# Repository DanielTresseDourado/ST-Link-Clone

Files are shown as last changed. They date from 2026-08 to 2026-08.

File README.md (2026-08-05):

# ST-Link Clone

Projeto desenvolvido na disciplina de Prototipagem do curso de Engenharia Elétrica da Universidade Estadual de Londrina (UEL).

Este repositório contém o desenvolvimento de uma placa compatível com o ST-Link para programação e depuração de microcontroladores STM32. O projeto foi concebido com foco na miniaturização do hardware e no desenvolvimento de uma PCB de alta densidade, empregando um encapsulamento Micro BGA e uma estrutura de seis camadas para atender aos requisitos de roteamento e integridade dos sinais.

## Placa

### Vista Superior
StLink top

### Vista Inferior
StLink bottom

## Conteúdo do repositório

- Projeto completo do Altium Designer
- Arquivos do projeto (.PrjPcb)
- Esquemáticos (.SchDoc)
- Layout da PCB (.PcbDoc)
- Bibliotecas de componentes esquemáticos e de PCB
- Arquivos de fabricação (Gerbers)

## Características

- Compatível com ST-Link para programação e depuração de microcontroladores STM32
- PCB de seis camadas
- Layout de alta densidade (HDI)
- Encapsulamento Micro BGA
- Formato compacto, com dimensões próximas às de um dongle USB
- Projeto desenvolvido no Altium Designer
- Documentação completa para edição e fabricação

## Autor

Daniel Tresse Dourado  
Engenharia Elétrica – Universidade Estadual de Londrina (UEL)

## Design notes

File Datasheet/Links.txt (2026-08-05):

micro STM32F103R8H6 -  https://www.digikey.com.br/en/products/detail/stmicroelectronics/STM32F103R8H6/2035336

Led Green - https://www.digikey.com.br/en/products/detail/w%C3%BCrth-elektronik/150040VS73240/8557157
Led Red - https://www.digikey.com.br/en/products/detail/w%C3%BCrth-elektronik/150040RS73240/8557156

Resistor Leds (0201) 560 ohm - https://www.digikey.com.br/en/products/detail/yageo/RC0201FR-07560RL/3202414

diodo schottky Single - https://www.digikey.com/en/products/detail/diodes-incorporated/BAT54WS-7-F/804865
resistor 0ohm(0201) - https://www.digikey.com.br/en/products/detail/yageo/RC0201JR-070RL/1948898

Capacitor 0.1uF - https://www.digikey.com/en/products/detail/murata-electronics/GRM155R71H104KE14D/4906220

Resistor 100k - https://www.digikey.com.br/en/products/detail/yageo/RC0201FR-07100KL/1948859

Resistor 1.5k - https://www.digikey.com.br/en/products/detail/yageo/RC0201JR-071K5L/1948919

Resistor 22 - https://www.digikey.com.br/en/products/detail/yageo/RC0201FR-0722RL/5280378

Resistor 100 - https://www.digikey.com/en/products/detail/yageo/RC0201FR-07100RL/1948860

Capacitor desacoplamento 100nF (0201) - https://www.digikey.com/en/products/detail/murata-electronics/GRM033R60J104KE19D/702433

Capacitor cristal 20pF (0210) - https://www.digikey.com/en/products/detail/murata-electronics/GRM0335C1H200GA01D/2542165

Regulador de tensao - https://www.digikey.com/en/products/detail/onsemi/NCP115AMX330TBG/9829206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

Capacitor 1uF p/ regulador - https://www.digikey.com/en/products/detail/murata-electronics/GRM033R60J105MEA2D/4213369

Cristal 8MHz - https://www.digikey.com/en/products/detail/ecs-inc/ECS-80-12-33-JGN-TR/10478754

USB A - https://www.digikey.com/en/products/detail/molex/0480372200/2421361?s=N4IgTCBcDaICwA4AMBmA7AWjGJSQF0BfIA

Conector 1x3 - https://www.digikey.com/en/products/detail/samtec-inc/T1M-03-F-SH-L/6692888

Resistor 10k - https://www.digikey.com/en/products/detail/yageo/RC0201FR-0710KL/1948870

Resistor 82 - https://www.digikey.com/en/products/detail/yageo/RC0201JR-0782RL/3202440

Capacitor 1uF 16V (0201) - https://www.digikey.com/en/products/detail/murata-electronics/GRM033R61C105ME15D/10326307

capacitor 15pF p/ cristal (0201) - https://www.digikey.com/en/products/detail/murata-electronics/GRM0335C1E150JA01D/4358179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

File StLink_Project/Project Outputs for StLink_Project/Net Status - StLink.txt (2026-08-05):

Net Status Report
Filename     : C:\Repos\1ELE909-Prototipagem\Assignment10\assignment10-stlinkcloneboardshapeandrouting-DanielTresseDourado\StLink_Project\StLink.PcbDoc
Date         : 11/06/2026
Time         : 13:34:05
Time Elapsed : 00:00:00

Nets, Layer, Length
    3.3V, Signal Layers Only, 0mm
    5V, Signal Layers Only, 0mm
    AIN 1, Signal Layers Only, 0mm
    GND, Signal Layers Only, 0mm
    LED STLINK, Signal Layers Only, 0mm
    NetC4_1, Signal Layers Only, 0mm
    NetCN1_1, Signal Layers Only, 1.575mm
    NetCN1_2, Signal Layers Only, 1.575mm
    NetD1_2, Signal Layers Only, 0mm
    NetD2_1, Signal Layers Only, 0mm
    NetD4_2, Signal Layers Only, 0mm
    NetR13_2, Signal Layers Only, 0mm
    NetR5_2, Signal Layers Only, 0mm
    NetR7_2, Signal Layers Only, 0mm
    NetR9_1, Signal Layers Only, 0mm
    OSC IN, Signal Layers Only, 0mm
    OSC OUT, Signal Layers Only, 0mm
    STM JTCK, Signal Layers Only, 0mm
    STM JTMS, Signal Layers Only, 0mm
    SWIM, Signal Layers Only, 0mm
    SWIM IN, Signal Layers Only, 0mm
    T JTCK, Signal Layers Only, 0mm
    T JTMS, Signal Layers Only, 0mm
    T SWDIO IN, Signal Layers Only, 0mm
    U5V, Signal Layers Only, 0mm
    USB DM, Signal Layers Only, 0mm
    USB DP, Signal Layers Only, 0mm
count : 27

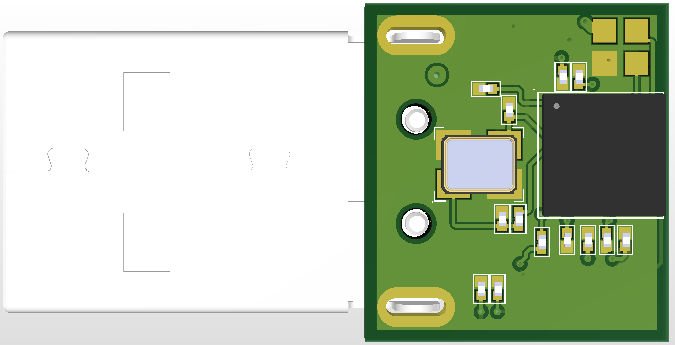
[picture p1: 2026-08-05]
StLink_Project/StLink bottom.png

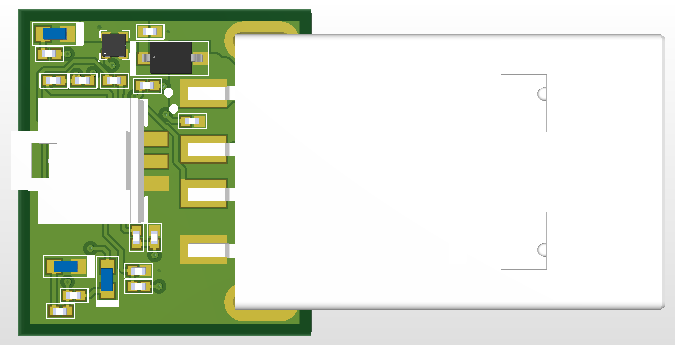
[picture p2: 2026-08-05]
StLink_Project/StLink top.png

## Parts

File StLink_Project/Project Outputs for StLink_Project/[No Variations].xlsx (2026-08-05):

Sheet: Part List Report
 | Component list |  |  | Bill of Materials for Project [StLink_Project.PrjPcb] (No PCB Document Selected)
 | Source Data From: | StLink_Project.PrjPcb |  |  | Contact: |  |  |  | Generated by:
 | Project: | StLink_Project.PrjPcb |  |  | <Parameter ClientCompanyName not found>
 | Variant: | None |  |  | <Parameter ClientContactName not found> |  |  |  | FEDEVEL
 |  |  |  |  | <Parameter ClientContactEmail not found>
 | Report Date: | 02/07/2026 | 21:43 |  | <Parameter ClientWebsite not found> |  |  |  | http://www.fedevel.com
 | Print Date: | 2026-07-02 | 18:33:52
# | Category | Manufacturer 1 | Manufacturer Part Number 1 | Case/Package | Description | Quantity | Supplier 1 | Supplier Part Number 1 | Supplier Order Qty 1 | Supplier Stock 1 | Supplier Unit Price 1 | Supplier Subtotal 1 | Supplier Currency 1
1 | Ceramic Capacitors | Murata | GRM033R60J104KE19D | 201 | 6.3V 100nF X5R ±10% 0201 Multilayer Ceramic Capacitors MLCC - SMD/SMT ROHS | 8 | DigiKey | 490-3167-6-ND | 8 | 14632707 | 0.10 | 0.80 | USD
2 | Ceramic Capacitors | Murata | GRM0335C1E150JA01D | 201 | 25V 15pF C0G ±5% 0201 Multilayer Ceramic Capacitors MLCC - SMD/SMT ROHS | 2 | DigiKey | 490-9658-2-ND | 2 | 224694 | 0.10 | 0.2 | USD
3 | Ceramic Capacitors | Murata | GRM033R61C105ME15D | 201 | 16V 1uF X5R ±20% 0201 Multilayer Ceramic Capacitors MLCC - SMD/SMT ROHS | 2 | DigiKey | 490-18654-1-ND | 2 | 4331 | 0.14 | 0.28 | USD
4 | Headers and Wire Housings | Samtec | T1M-03-F-SH-L |  | Conn Shrouded Header (4 Sides) HDR 3 POS 1mm Solder RA Side Entry SMD Micro Mate™ Bulk | 1 | DigiKey | 612-T1M-03-F-SH-LCT-ND | 1 | 626 | 2.07 | 2.07 | USD
5 | USB Connectors | Molex | 48037-2200 |  | USB Connector, 4 Contact(s), Male, Right Angle, Surface Mount Terminal, Locking, Plug | 1 | DigiKey | WM3983DKR-ND | 1 | 8267 | 1.32 | 1.32 | USD
6 | LEDs | Wurth Elektronik | 150040RS73240 | 402 | Wurth Elektronik LED, WL-SMCC, 1005 (0402), 625 nm, 1 x 0.5 x 0.4mm | 2 | DigiKey | 732-11991-1-ND | 2 | 35530 | 0.32 | 0.64 | USD
7 | LEDs | Wurth Elektronik | 150040VS73240 | 402 | Wurth Elektronik LED, WL-SMCC, 1005 (0402), 570 nm, 1 x 0.5 x 0.4mm | 1 | DigiKey | 732-11992-1-ND | 1 | 57790 | 0.32 | 0.32 | USD
8 | Schottky Diodes | Diodes Inc. | BAT54WS-7-F |  | Schottky Diode Sod323 T&r 3K Rohs Compliant: Yes |Diodes Inc. BAT54WS-7-F | 1 | DigiKey | BAT54WS-FDICT-ND | 1 | 202277 | 0.20 | 0.20 | USD
9 | Chip SMD Resistors | Yageo Group | RC0201FR-07100RL | 201 | 50mW Thick Film Resistors 25V ±1% ±200ppm/℃ 100Ω 0201 Chip Resistor - Surface Mount ROHS | 3 | DigiKey | 311-100MCT-ND | 3 | 910628 | 0.10 | 0.30 | USD
10 | Chip SMD Resistors | Yageo Group | RC0201JR-0782RL | 201 | Res Thick Film 0201 82 Ohm 5% 0.05W(1/20W) ±200ppm/C Pad SMD T/R | 4 | DigiKey | YAG2365CT-ND | 4 | 21705 | 0.10 | 0.40 | USD
11 | Chip SMD Resistors | Yageo Group | RC0201FR-071KL | 201 | Res Thick Film 0201 1K Ohm 1% 0.05W(1/20W) ±200ppm/C Pad SMD T/R | 4 | DigiKey | 311-1KMCT-ND | 4 | 2780145 | 0.10 | 0.40 | USD
12 | Chip SMD Resistors | Yageo Group | RC0201JR-071K5L | 201 | Res Thick Film 0201 1.5K Ohm 5% 0.05W(1/20W) ±200ppm/C Pad SMD T/R | 1 | DigiKey | 311-1.5KNCT-ND | 1 | 218602 | 0.10 | 0.10 | USD
13 | Chip SMD Resistors | Yageo Group | RC0201FR-07100KL | 201 | 50mW Thick Film Resistors 25V ±1% ±200ppm/℃ 100kΩ 0201 Chip Resistor - Surface Mount ROHS | 1 | DigiKey | 311-100KMDKR-ND | 1 | 1801099 | 0.10 | 0.10 | USD
14 | Microcontrollers | STMicroelectronics | STM32F103R8H6 | FBGA | MCU 32-bit STM32F ARM Cortex M3 RISC 64KB Flash 2.5V/3.3V 64-Pin TFBGA Tray | 1 | DigiKey | 497-11523-ND |  | 0 |  |  | USD
15 | LDO Voltage Regulators | Diodes Inc. | AP7343D-33FS4-7B |  | Ldo, Fixed, 3.3V, 0.3A, -40 To 85Deg C Rohs Compliant: Yes |Diodes Inc. AP7343D-33FS4-7B | 1 | DigiKey | AP7343D-33FS4-7BDICT-ND | 1 | 9533 | 0.12 | 0.12 | USD
16 | Crystals | ECS Inc. | ECS-80-12-33-JGN-TR |  | Crystal 8MHz ±20ppm (Tol) ±30ppm (Stability) 12pF FUND 400Ohm 4-Pin Mini-CSMD T/R | 1 | DigiKey | 50-ECS-80-12-33-JGN-TR-ND | 1 | 7085 | 0.58 | 0.58 | USD
 |  |  |  |  |  | 34 |  |  | 33 |  |  | 7.83
Approved |  |  |  | Notes
 |  |  |  |  |  | 1 | pcs: | Total |  | 7.83 |  | USD
 |  |  |  |  |  |  |  | Price for 1pcs |  | 7.83 |  | USD

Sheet: Project Information
Project Full Path | D:\Repos\Proto\assingment12-stlinkclonefinal-LeviMonteiro\StLink_Project\StLink_Project.PrjPcb
Project Filename | StLink_Project.PrjPcb
Variant Name | None
Data-Source Filename | StLink_Project.PrjPcb
Data-Source Full Path | D:\Repos\Proto\assingment12-stlinkclonefinal-LeviMonteiro\StLink_Project\StLink_Project.PrjPcb
Title | Bill of Materials for Project [StLink_Project.PrjPcb] (No PCB Document Selected)
Total Quantity | 38
Report Time | 21:43
Report Date | 02/07/2026
Report Date & Tine | 02/07/2026 21:43
Output Name | Bill of Materials
Output Type | BomReport
Output Generator Name | BOM
Output Generator Description | Bill of Materials

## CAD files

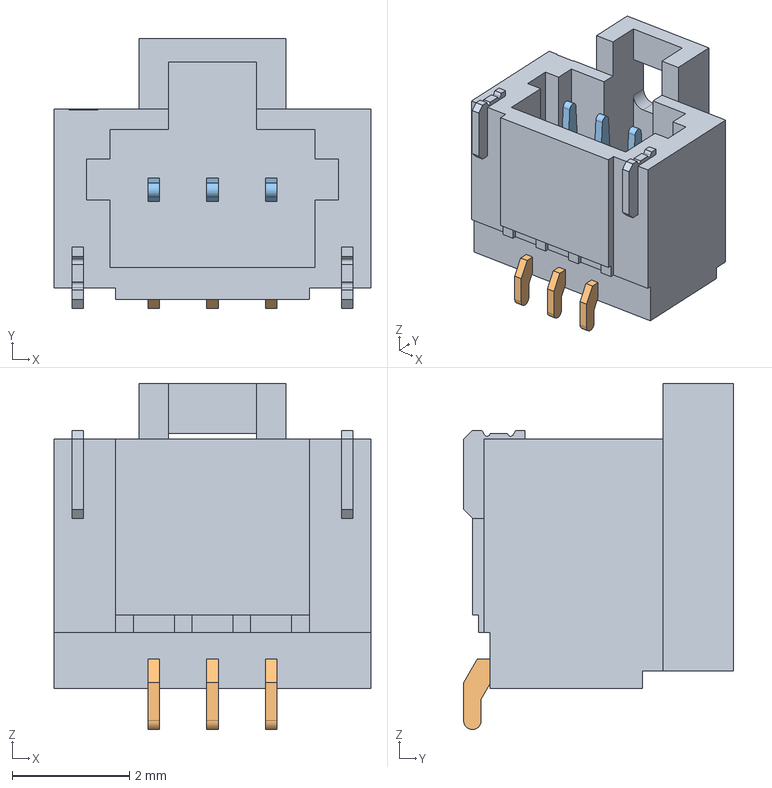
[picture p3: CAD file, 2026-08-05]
StLink_Project/3D_Model/T1M-03-F-SH-L.stp
5.40 x 4.60 x 5.90 mm
T1T1M-03-T-SH-L
P2T1M-03-F-SH-L
P22T1M-03-F-SH-L

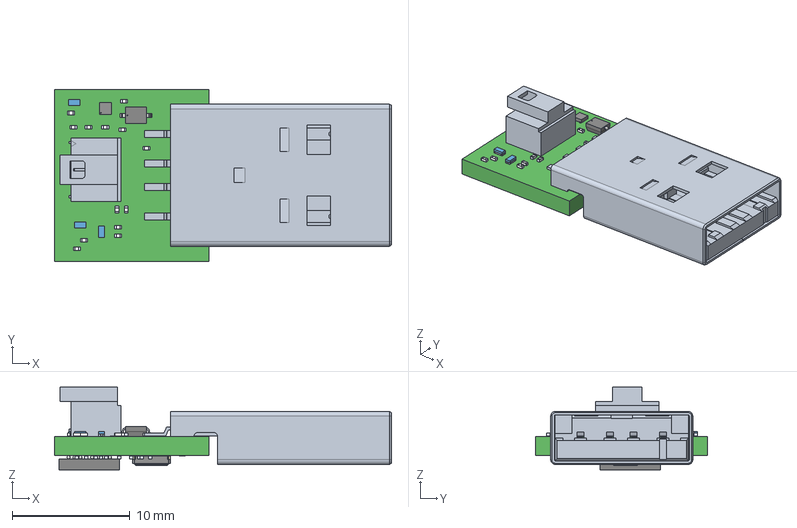
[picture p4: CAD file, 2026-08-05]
StLink_Project/Project Outputs for StLink_Project/Export STEP/[No Variations].step
28.6 x 14.6 x 7.00 mm
RC0201FR-07560RL x 26
T1T1M-03-T-SH-L
P2T1M-03-F-SH-L
P22T1M-03-F-SH-L
Contact x 24
Linse x 27
SOD323_DIO
TLV70718PDQNR
ECS-80-12-33-JGN-TR

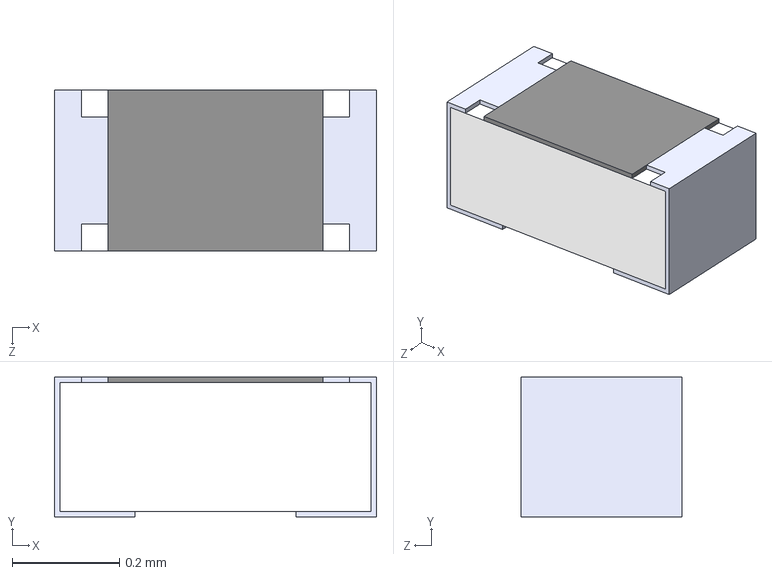
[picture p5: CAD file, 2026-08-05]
StLink_Project/3D_Model/RC0201FR-07560RL.STEP
0.6 x 0.26 x 0.3 mm

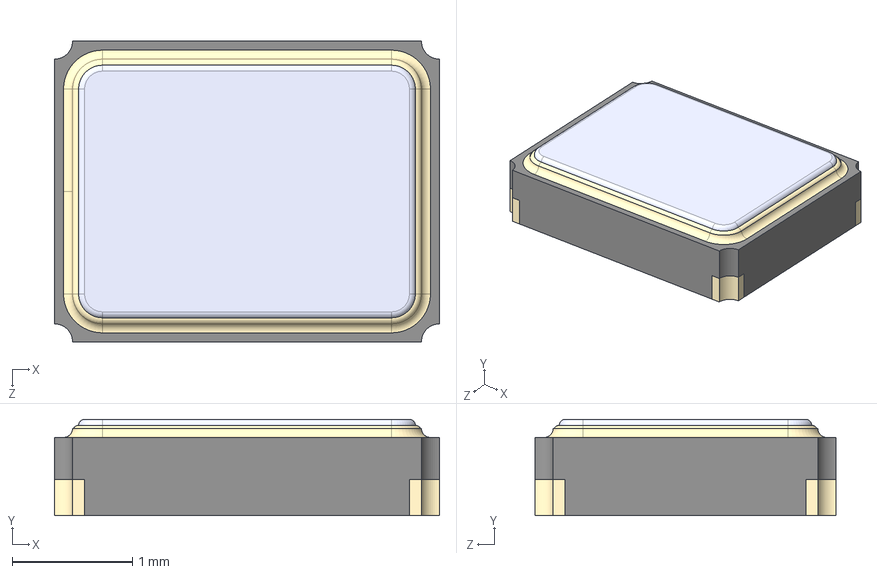
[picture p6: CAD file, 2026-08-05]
StLink_Project/3D_Model/ECS-80-12-33-JGN-TR.STEP
3.20 x 0.8 x 2.50 mm

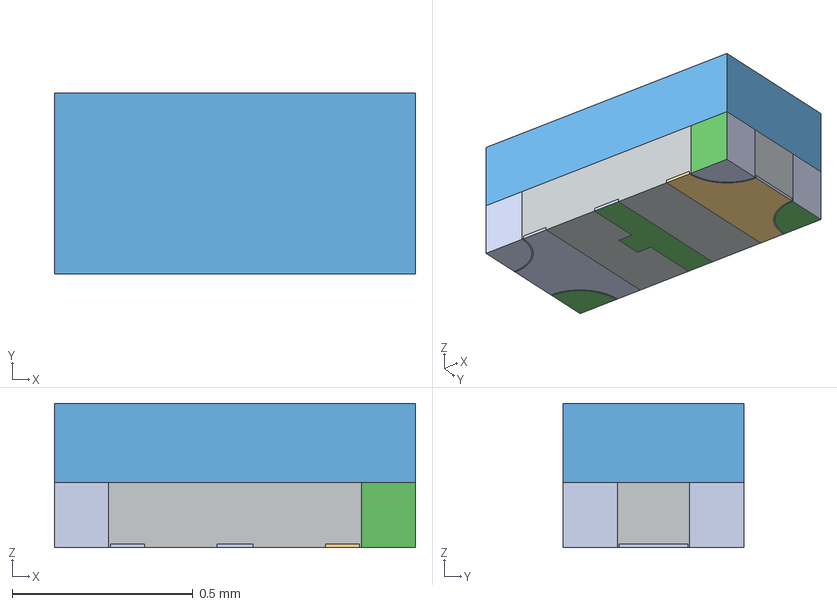
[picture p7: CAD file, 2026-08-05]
StLink_Project/3D_Model/Download_STP_WL-SMCC-0402+%28rev1%29.stp
1.00 x 0.5 x 0.4 mm
Contact x 8
Linse x 9

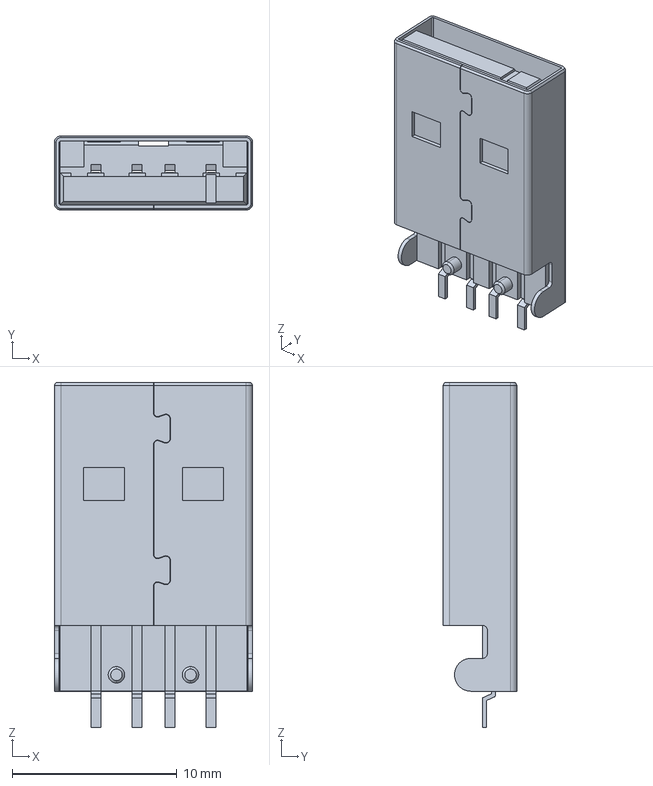
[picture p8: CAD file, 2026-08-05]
StLink_Project/3D_Model/480372200.stp
12.1 x 4.50 x 21.0 mm

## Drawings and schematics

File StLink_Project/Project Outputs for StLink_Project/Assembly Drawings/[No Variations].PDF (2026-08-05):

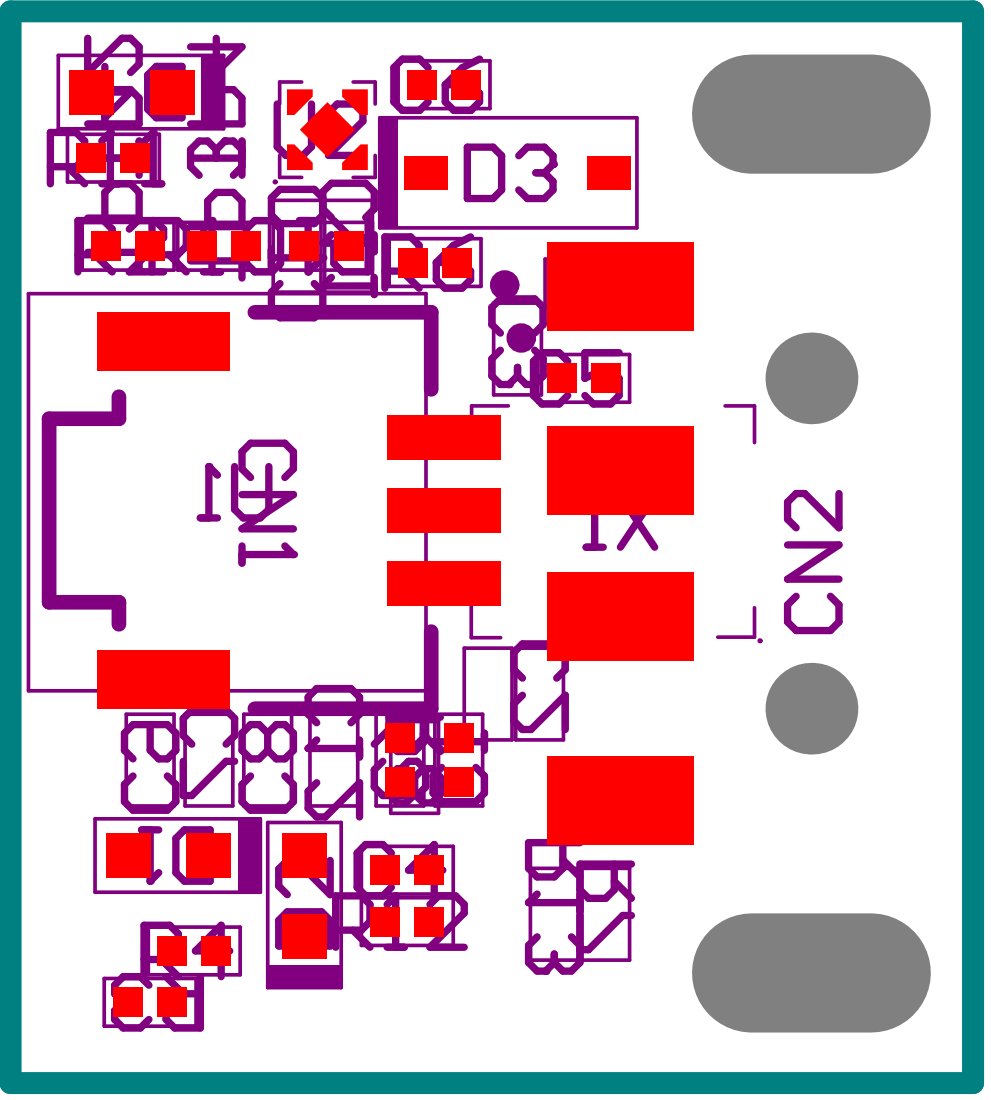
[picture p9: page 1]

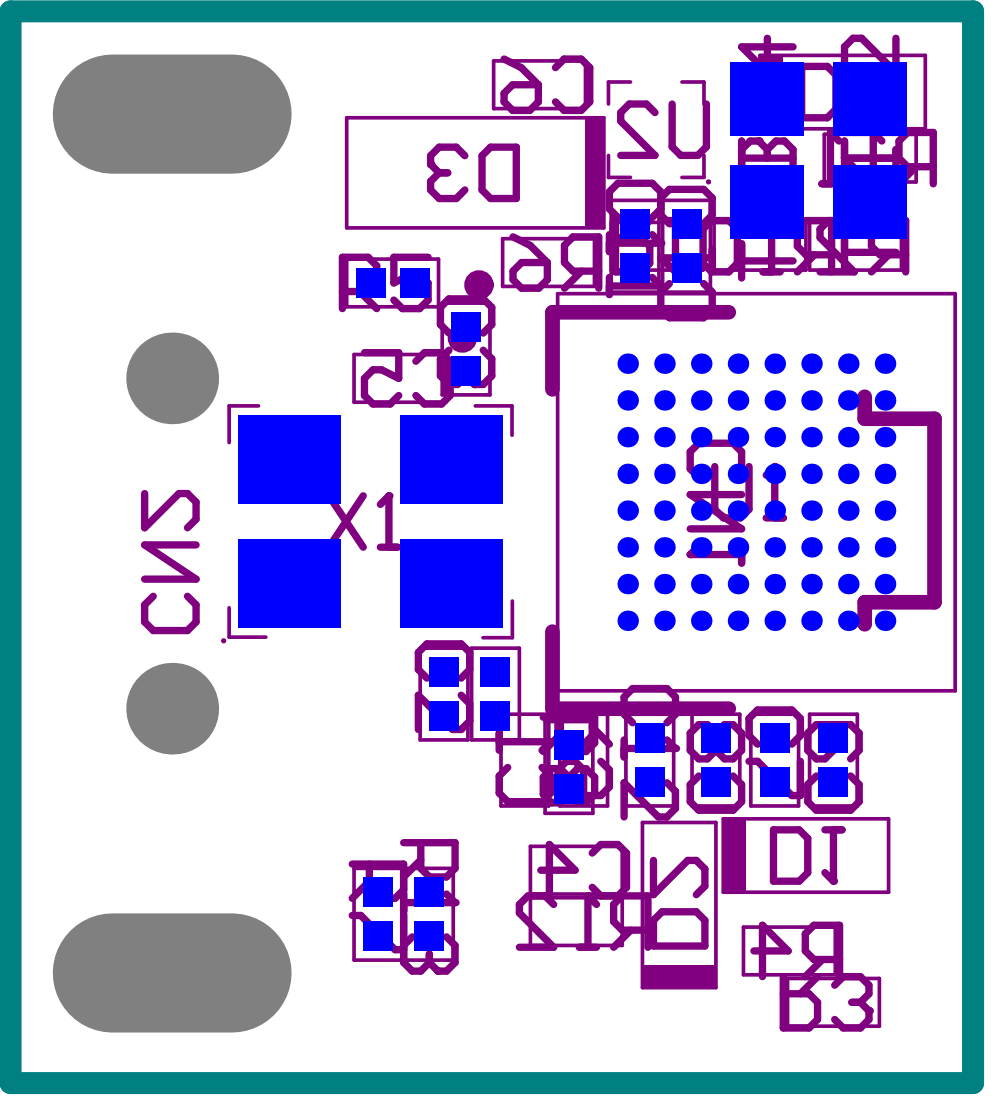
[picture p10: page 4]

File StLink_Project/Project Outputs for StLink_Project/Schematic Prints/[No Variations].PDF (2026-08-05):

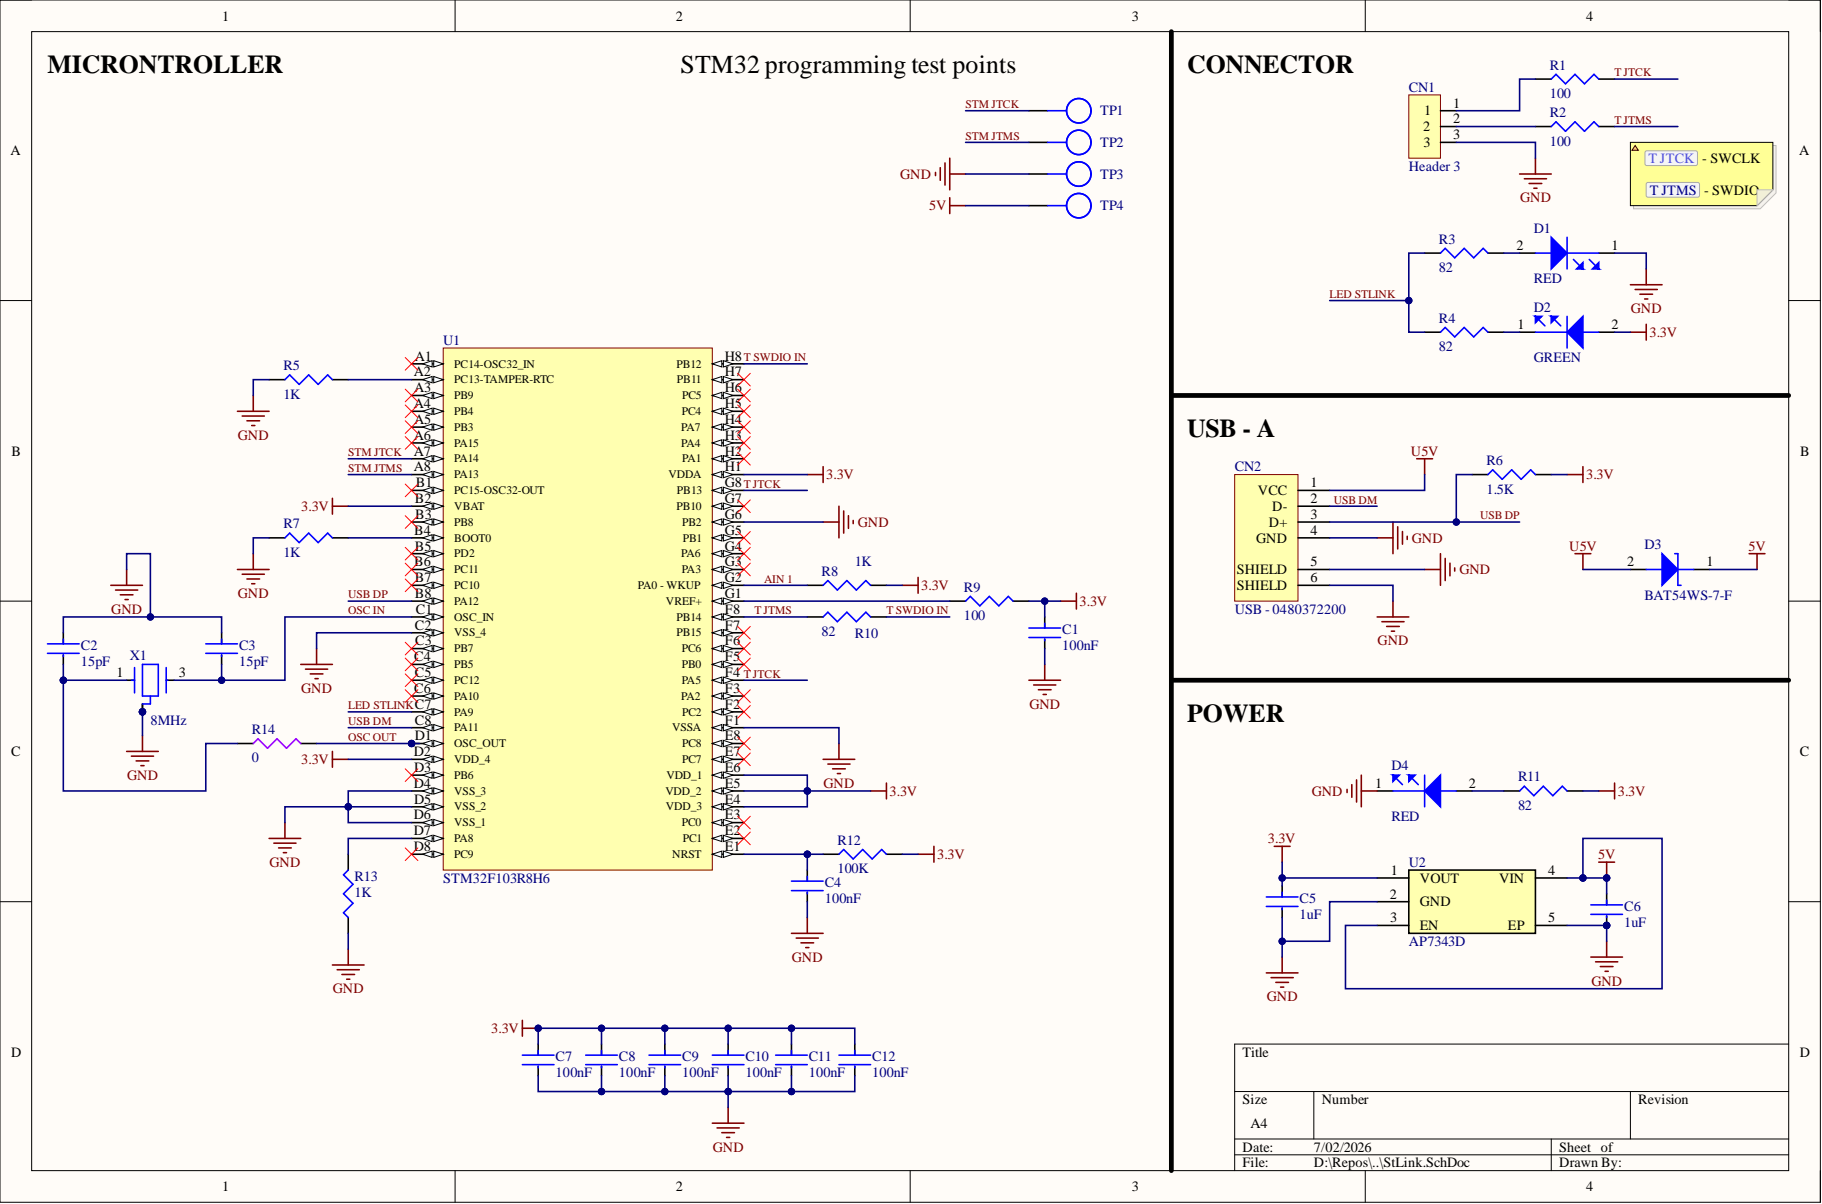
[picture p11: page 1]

VSS_4 C2
PB7 C3
PB5 C4

VSS_2 D5
VSS_1 D6

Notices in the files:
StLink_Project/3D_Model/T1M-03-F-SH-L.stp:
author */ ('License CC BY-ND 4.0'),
